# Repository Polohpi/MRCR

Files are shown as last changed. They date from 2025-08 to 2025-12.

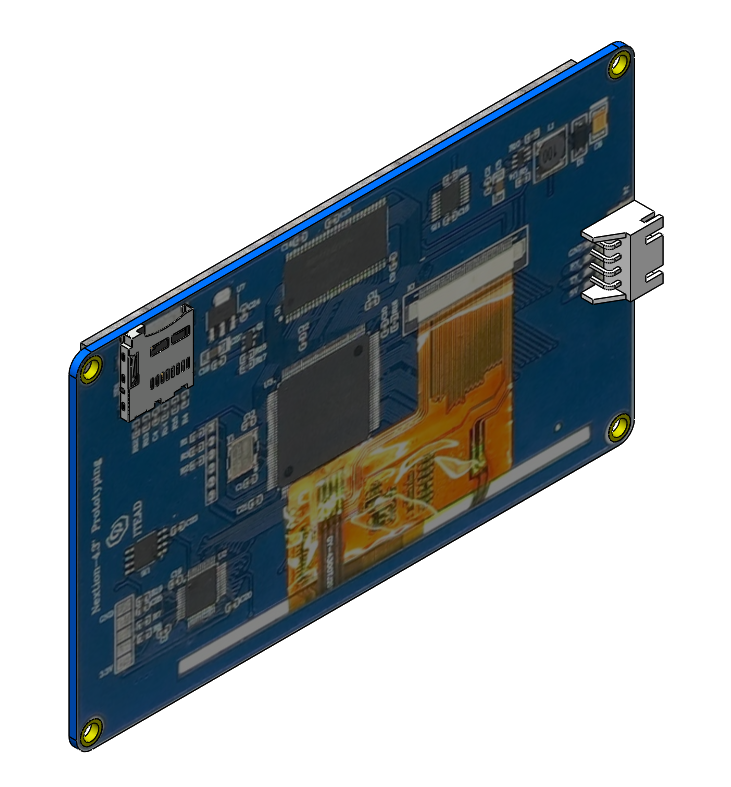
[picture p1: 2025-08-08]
Nextion/Sldprt/Capture3.PNG

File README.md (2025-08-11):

# MRCR
Banc de Rodage pour moteur Nitro

Arduino SAMD21 M0

using :

PID_v1 library            https://github.com/br3ttb/Arduino-PID-Library
Scheduler                 https://github.com/arduino-libraries/Scheduler
Easy Nextion Library      https://github.com/Seithan/EasyNextionLibrary
MovingAvg                  https://github.com/JChristensen/movingAvg

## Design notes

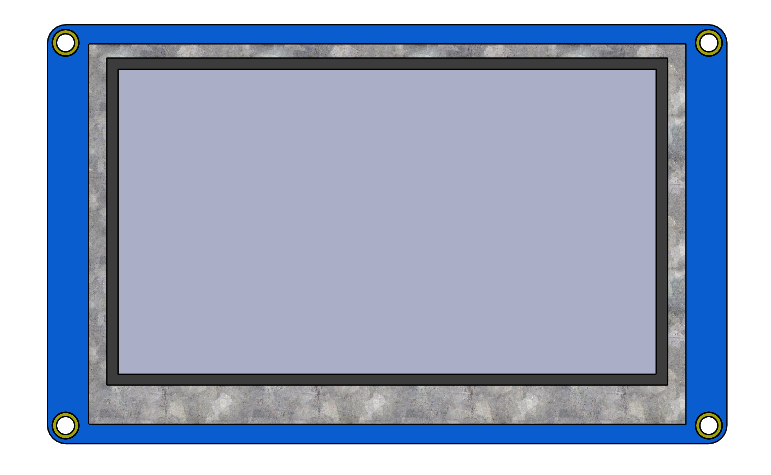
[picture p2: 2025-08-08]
Nextion/Sldprt/Capture1.PNG

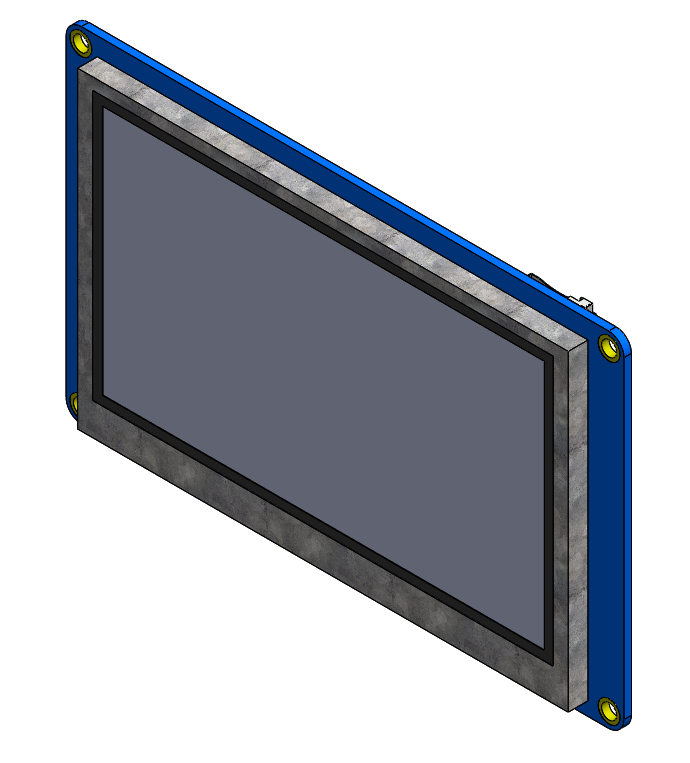
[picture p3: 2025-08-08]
Nextion/Sldprt/Capture2.PNG

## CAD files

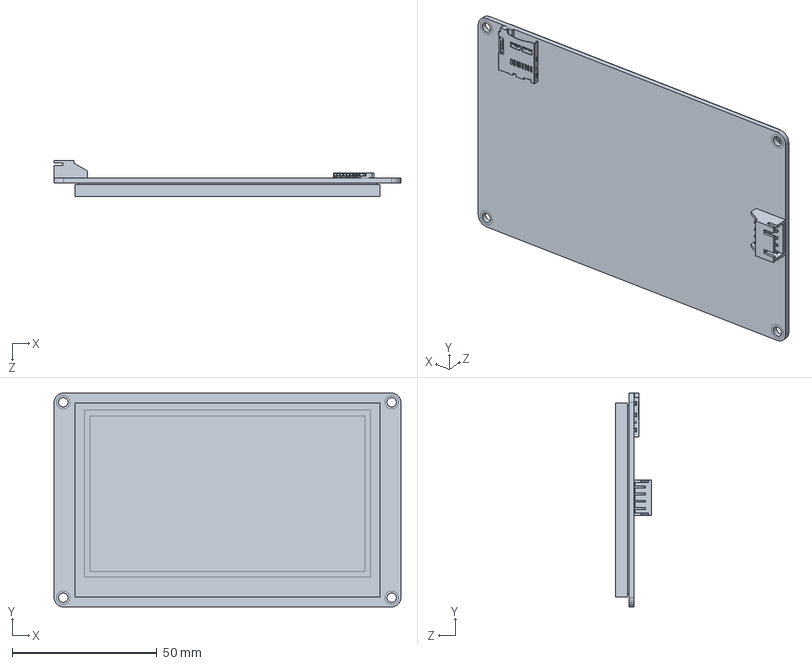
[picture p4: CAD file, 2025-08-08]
Nextion/Sldprt/Nextion - NX4827T043_011 - 4.3inch HMI LCD Screen.SLDPRT
120.0 x 74.0 x 12.5 mm

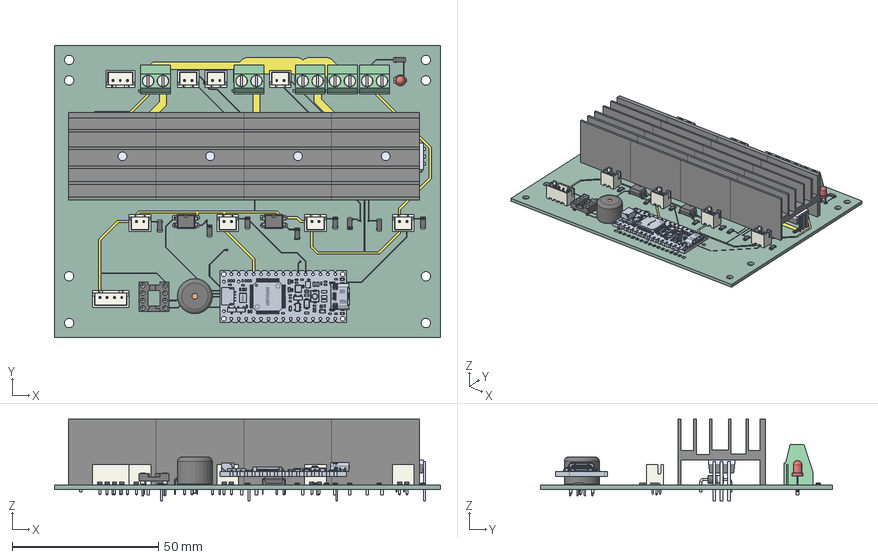
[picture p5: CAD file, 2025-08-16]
PCB/banc_rodage_pcb/banc_rodage_pcb.step
132.0 x 100.0 x 28.0 mm
R_1206_3216Metric x 11
banc_rodage_pcb 1.2.1
banc_rodage_pcb 1.2.2
banc_rodage_pcb 1.2.3
banc_rodage_pcb 1.2.4
banc_rodage_pcb 1.2.5
banc_rodage_pcb 1.2.6
banc_rodage_pcb 1.2.7
banc_rodage_pcb 1.2.8
banc_rodage_pcb 1.2.9
banc_rodage_pcb 1.2.10
banc_rodage_pcb 1.2.11
banc_rodage_pcb 1.2.12
banc_rodage_pcb 1.2.13
banc_rodage_pcb 1.2.14
banc_rodage_pcb 1.2.15
banc_rodage_pcb 1.2.16
banc_rodage_pcb 1.2.17
banc_rodage_pcb 1.2.18
banc_rodage_pcb 1.2.19
banc_rodage_pcb 1.2.20
banc_rodage_pcb 1.2.21
banc_rodage_pcb 1.2.22
banc_rodage_pcb 1.2.23
banc_rodage_pcb 1.2.24
banc_rodage_pcb 1.2.25
banc_rodage_pcb 1.2.26
banc_rodage_pcb 1.2.27
banc_rodage_pcb 1.2.28
banc_rodage_pcb 1.2.29
banc_rodage_pcb 1.2.30
banc_rodage_pcb 1.2.31
banc_rodage_pcb 1.2.32
banc_rodage_pcb 1.2.33
banc_rodage_pcb 1.2.34
banc_rodage_pcb 1.2.35
banc_rodage_pcb 1.2.36
banc_rodage_pcb 1.2.37
banc_rodage_pcb 1.2.38
banc_rodage_pcb 1.2.39
banc_rodage_pcb 1.2.40
banc_rodage_pcb 1.2.41
banc_rodage_pcb 1.2.42
banc_rodage_pcb 1.2.43
banc_rodage_pcb 1.2.44
banc_rodage_pcb 1.2.45
banc_rodage_pcb 1.2.46
banc_rodage_pcb 1.2.47
banc_rodage_pcb 1.2.48
banc_rodage_pcb 1.2.49
banc_rodage_pcb 1.2.50
banc_rodage_pcb 1.2.51
banc_rodage_pcb 1.2.52
banc_rodage_pcb 1.2.53
banc_rodage_pcb 1.2.54
banc_rodage_pcb 1.2.55
banc_rodage_pcb 1.2.56
banc_rodage_pcb 1.2.57
banc_rodage_pcb 1.2.58
banc_rodage_pcb 1.2.59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

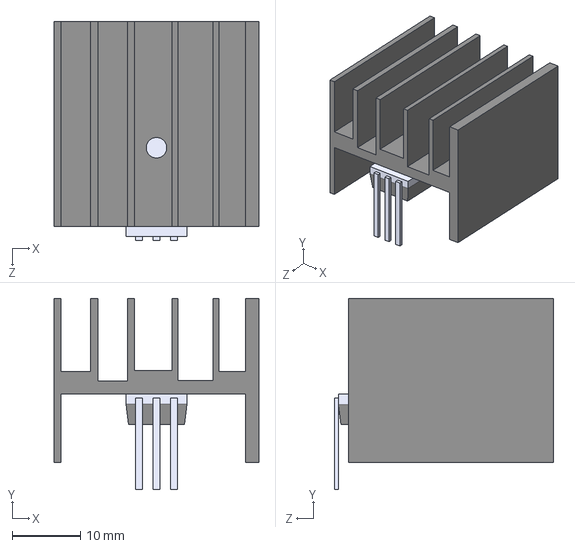
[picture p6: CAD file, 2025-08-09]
PCB/kicad library/Part1.STEP
30.0 x 28.0 x 32.1 mm

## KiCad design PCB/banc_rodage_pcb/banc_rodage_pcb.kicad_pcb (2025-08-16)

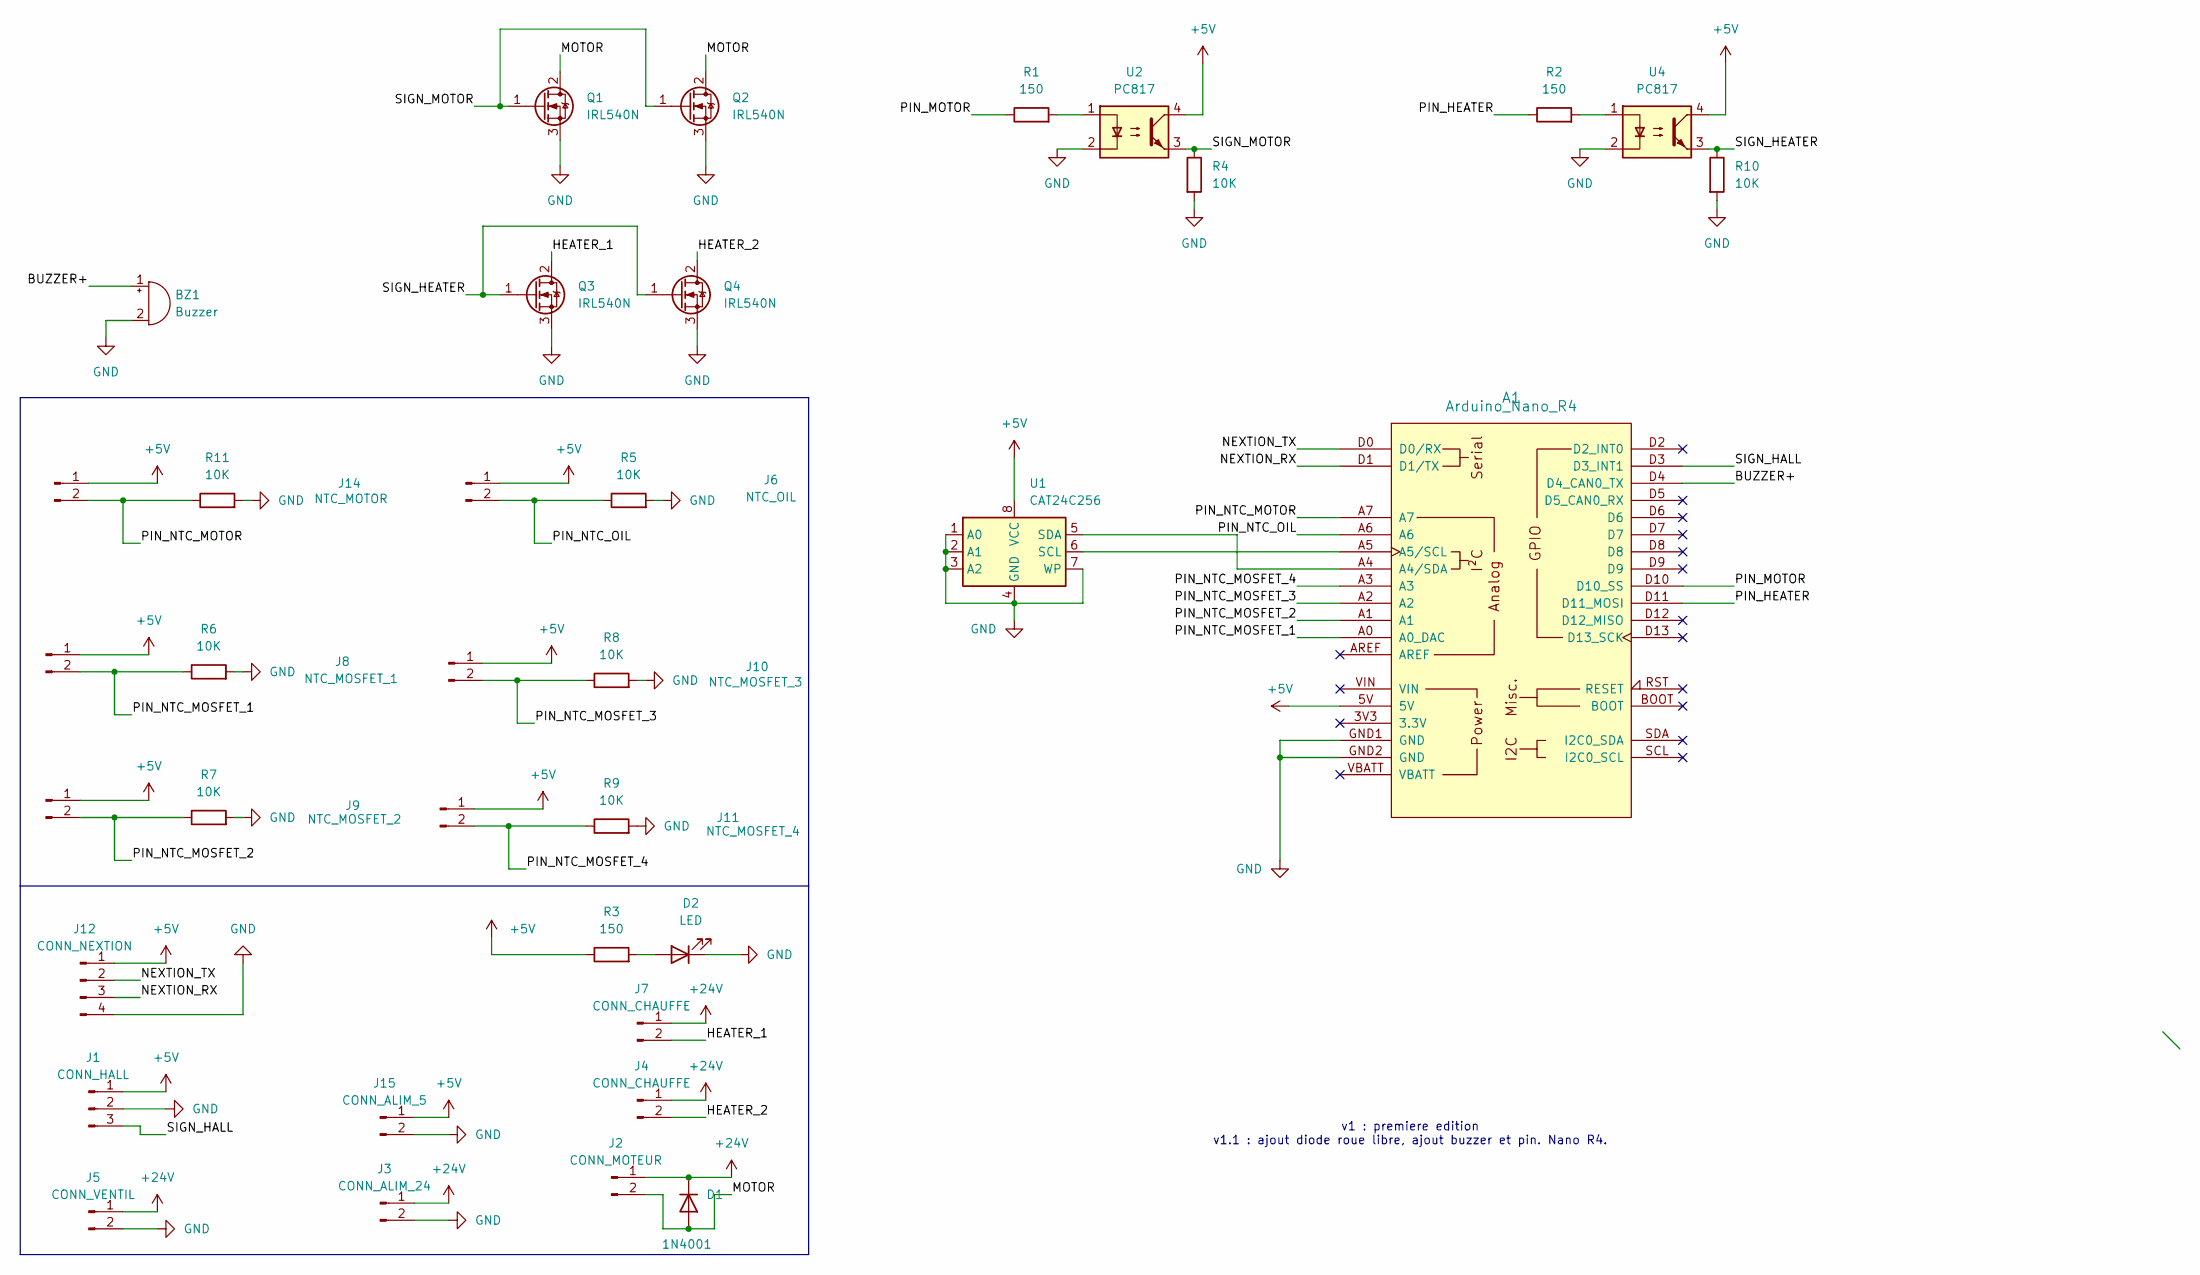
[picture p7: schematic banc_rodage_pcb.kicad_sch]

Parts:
A1: Arduino_Nano_R4
BZ1: Buzzer; Buzzer_12x9.5RM7.6
D1: 1N4001; D_DO-41_SOD81_P10.16mm_Horizontal
D2: LED; LED_D3.0mm
J1: CONN_HALL; JST_XH_B3B-XH-A_1x03_P2.50mm_Vertical
J2: CONN_MOTEUR; TerminalBlock_bornier-2_P5.08mm
J3: CONN_ALIM_24; TerminalBlock_bornier-2_P5.08mm
J4, J7: CONN_CHAUFFE; TerminalBlock_bornier-2_P5.08mm
J5: CONN_VENTIL; JST_XH_B2B-XH-A_1x02_P2.50mm_Vertical
J6: NTC_OIL; JST_XH_B2B-XH-A_1x02_P2.50mm_Vertical
J8: NTC_MOSFET_1; JST_XH_B2B-XH-A_1x02_P2.50mm_Vertical
J9: NTC_MOSFET_2; JST_XH_B2B-XH-A_1x02_P2.50mm_Vertical
J10: NTC_MOSFET_3; JST_XH_B2B-XH-A_1x02_P2.50mm_Vertical
J11: NTC_MOSFET_4; JST_XH_B2B-XH-A_1x02_P2.50mm_Vertical
J12: CONN_NEXTION; JST_XH_B4B-XH-A_1x04_P2.50mm_Vertical
J14: NTC_MOTOR; JST_XH_B2B-XH-A_1x02_P2.50mm_Vertical
J15: CONN_ALIM_5; TerminalBlock_bornier-2_P5.08mm
Q1, Q2, Q3, Q4: IRL540N; TO-220F-3_Horizontal_TabUp
R1, R2, R3: 150; R_1206_3216Metric
R4, R5, R6, R7, R8, R9, R10, R11: 10K; R_1206_3216Metric
U1: CAT24C256; DIP-8_W7.62mm_Socket
U2, U4: PC817; DIP-4_W7.62mm

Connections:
+5V: A1.5V, J1.1, J6.1, J8.1, J9.1, J10.1, J11.1, J12.1, J14.1, J15.1, R3.1, U1.8 (VCC), U2.4, U4.4
+24V: D1.1 (K), J2.1, J3.1, J4.1, J5.1, J7.1
/BUZZER+: A1.D4 (D4_CAN0_TX), BZ1.1 (+)
/HEATER_1: J7.2, Q3.2 (D)
/HEATER_2: J4.2, Q4.2 (D)
/MOTOR: D1.2 (A), J2.2, Q1.2 (D), Q2.2 (D)
/NEXTION_RX: A1.D1 (D1/TX), J12.3
/NEXTION_TX: A1.D0 (D0/RX), J12.2
/PIN_HEATER: A1.D11 (D11_MOSI), R2.1
/PIN_MOTOR: A1.D10 (D10_SS), R1.1
/PIN_NTC_MOSFET_1: A1.A0 (A0_DAC), J8.2, R6.1
/PIN_NTC_MOSFET_2: A1.A1, J9.2, R7.1
/PIN_NTC_MOSFET_3: A1.A2, J10.2, R8.1
/PIN_NTC_MOSFET_4: A1.A3, J11.2, R9.1
/PIN_NTC_MOTOR: A1.A7, J14.2, R11.1
/PIN_NTC_OIL: A1.A6, J6.2, R5.1
/SIGN_HALL: A1.D3 (D3_INT1), J1.3
/SIGN_HEATER: Q3.1 (G), Q4.1 (G), R10.1, U4.3
/SIGN_MOTOR: Q1.1 (G), Q2.1 (G), R4.1, U2.3
GND: A1.GND1 (GND), A1.GND2 (GND), BZ1.2 (-), D2.1 (K), J1.2, J3.2, J5.2, J12.4, J15.2, Q1.3 (S), Q2.3 (S), Q3.3 (S), Q4.3 (S), R4.2, R5.2, R6.2, R7.2, R8.2, R9.2, R10.2, R11.2, U1.1 (A0), U1.2 (A1), U1.3 (A2), U1.4 (GND), U1.7 (WP), U2.2, U4.2
unnamed: A1.A4 (A4/SDA), U1.5 (SDA)
unnamed: A1.A5 (A5/SCL), U1.6 (SCL)
unnamed: D2.2 (A), R3.2
unnamed: R1.2, U2.1
unnamed: R2.2, U4.1

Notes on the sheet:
v1 : premiere edition v1.1 : ajout diode roue libre, ajout buzzer et pin. Nano R4.

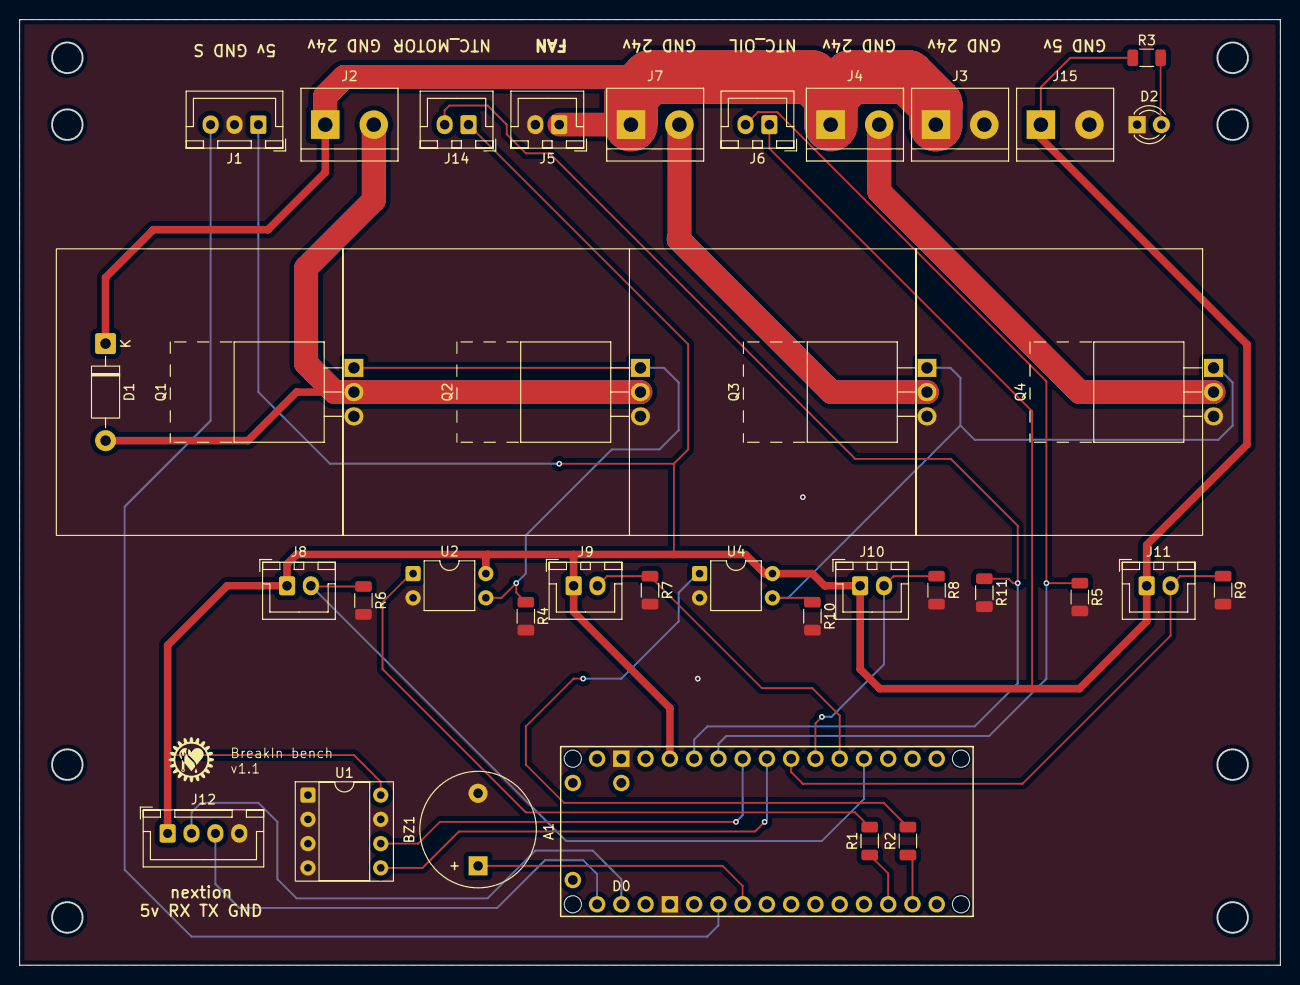
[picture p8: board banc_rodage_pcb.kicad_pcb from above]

Board: 2 copper layers, 132.0 x 99.0 mm, 36 parts (0 on the bottom side), 25 nets.

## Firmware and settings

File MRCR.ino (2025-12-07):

#include "lib_variable.h"
#include "function_software.h"
#include "function_hardware.h"
#include "page.h"
#include "function_nextion.h"



void setup() {
  
  analogWriteResolution(12); //14 because 16 make the PID and the motor very very long to respond
  Serial.begin(9600);
  Nextion.begin(9600); // Begin the object with a baud rate of 9600


  Serial.println("Setup");
  Scheduler.startLoop(ntc_update);
  Scheduler.startLoop(backend_nextion);
  Scheduler.startLoop(MOTOR_PID);
  Scheduler.startLoop(RPM_update);
  Scheduler.startLoop(HEAT_ramp);
  Scheduler.startLoop(debug, 2048);
  Scheduler.startLoop(Manual_Timer);
  Scheduler.startLoop(Security);
  Scheduler.startLoop(MainPage);
  Scheduler.startLoop(ManualModePage);


  Motor_PID.SetMode(AUTOMATIC);

  Motor_PID.SetOutputLimits(0, 6700); //see backend_PID()
  
  Avg_Temp_ntc_oil.begin(); // start movingavg for heating, motor and ntc sensor
  Avg_MotorRPM.begin();
  Avg_Temp_ntc_mosfet_motor_1.begin();
  Avg_Temp_ntc_mosfet_motor_2.begin();
  Avg_Temp_ntc_motor.begin();
  Avg_Temp_ntc_mosfet_heat_1.begin();
  Avg_Temp_ntc_mosfet_heat_2.begin();
  Avg_MotorRPM.reset();

  pinMode(PIN_NTC_MOSFET_MOTOR_1, INPUT);      // set pinmode
  pinMode(PIN_NTC_MOSFET_MOTOR_2, INPUT);
  pinMode(PIN_NTC_MOSFET_HEAT_1, INPUT);
  pinMode(PIN_NTC_MOSFET_HEAT_2, INPUT);
  pinMode(PIN_NTC_MOTOR, INPUT); //pullup here to avaoid erratic reaing before the pcb v2 wich will include a ntc sensor for the DC motor itself
  pinMode(PIN_NTC_OIL, INPUT);
  pinMode(PIN_MOTOR, OUTPUT);
  pinMode(PIN_HEATER, OUTPUT); 
  pinMode(PIN_IR_SENSOR, INPUT_PULLUP);

  attachInterrupt(digitalPinToInterrupt(PIN_IR_SENSOR), RPM_interrupt, FALLING);
  yield();
  delay(2000);
}

void loop() 
{

  if(MAIN_PAGE == false && MANUAL_MODE_PAGE == false)
  {
  Nextion.writeStr("page Main");
  MAIN_PAGE = true;
  }
  yield();
}

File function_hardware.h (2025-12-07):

#ifndef FUNCTION_HARDWARE_H
#define FUNCTION_HARDWARE_H


void MOTOR_PID();
void backend_nextion();
void ntc_update();
void RPM_interrupt();
void HEAT_ramp();



//compute the PID for the motor
void MOTOR_PID()
{
  if( (millis() - Motor_PID_refresh_timer) > MOTOR_PID_REFRESH_TIME)
  {

      if(Motor_Setpoint == 0)
      {
        /*
        The PID library doesnt include a function to force the pid output to 0. The output only change based on the input and tthe output.
        This means when we set output == 0 when Setpoint == 0 (to stop the motor), the ouput comput from the pid dont go to 0.
        Logic : the RPM = 0 and the setpoint = 0 so no need the change the output. We will lure the PID with a constant high RPM so it will go to 0.
        */
        Motor_PID.Compute();
      }
      else
      {
        if(Emergency_stop == false)
        {
          Motor_PID.Compute();
        }
      }
      analogWrite(PIN_MOTOR, (Motor_Output/10)*( (Motor_Output/6000)*(Motor_Output/6000)* 20) ); 
      Motor_PID_refresh_timer = millis();

      /* this weird line is not my fault I promess. 
      The problem is : the pid can control most of the speed of the motor (0 RPM<output<~ 550 RPM) 
      but can not manage to get the motor to run to 1200 RPM. This take ages.
      This was the only solution I got to work without make the PID unstable. So i fix it with some duck tape I guess */
    
  } 
  yield();

}

//manage all global data flow between MCU and nextion
void backend_nextion()
{
  if( (millis() - nextion_response_refresh_timer) > NEXTION_RESPONSE_REFRESH_TIME)
  {
    //send current RPM and oil temp
    Nextion.writeNum("GLB_VAL.CUR_RPM.val", avg_Motor_RPM);
    Nextion.writeNum("GLB_VAL.CUR_HEAT.val",  avg_temp_ntc_oil);

    //send all temp values from security NTC sensor
    Nextion.writeNum("GLB_VAL.NTC_MTR1.val",  avg_temp_ntc_mosfet_motor_1);
    Nextion.writeNum("GLB_VAL.NTC_MTR2.val",  avg_temp_ntc_mosfet_motor_2);
    Nextion.writeNum("GLB_VAL.NTC_MTR.val",  avg_temp_ntc_motor);
    Nextion.writeNum("GLB_VAL.NTC_HTR1.val",  avg_temp_ntc_mosfet_heat_1);
    Nextion.writeNum("GLB_VAL.NTC_HTR2.val",  avg_temp_ntc_mosfet_heat_1);

    //send PID output
    Nextion.writeNum("GLB_VAL.MTR_OTP.val",  Motor_Output);
    Nextion.writeNum("GLB_VAL.IR_SNSR.val",  IR_sensor_count);
    Nextion.writeStr("GLB_VAL.HEAT_STE.txt",  digitalRead(PIN_HEATER) ? "ON" : "OFF");


    current_year = Nextion.readNumber("GLB_VAL.CUR_YEAR.val");
    current_month = Nextion.readNumber("GLB_VAL.CUR_MONTH.val");
    current_day = Nextion.readNumber("GLB_VAL.CUR_DAY.val");
    current_hour = Nextion.readNumber("GLB_VAL.CUR_HOUR.val");
    current_minute = Nextion.readNumber("GLB_VAL.CUR_MIN.val");
    current_second = Nextion.readNumber("GLB_VAL.CUR_SEC.val");

    Nextion.NextionListen();
    nextion_response_refresh_timer = millis();
  }
  yield();
}


//update all ntc temperature
void ntc_update()
{
  if( (millis() - NTC_refresh_timer) > NTC_REFRESH_TIME)
  {
    avg_temp_ntc_oil = Avg_Temp_ntc_oil.reading(ReadTempNTC(PIN_NTC_OIL));
    avg_temp_ntc_motor = Avg_Temp_ntc_motor.reading(ReadTempNTC(PIN_NTC_MOTOR));
    avg_temp_ntc_mosfet_motor_1 = Avg_Temp_ntc_mosfet_motor_1.reading(ReadTempNTC(PIN_NTC_MOSFET_MOTOR_1));
    avg_temp_ntc_mosfet_motor_2 = Avg_Temp_ntc_mosfet_motor_2.reading(ReadTempNTC(PIN_NTC_MOSFET_MOTOR_2));
    avg_temp_ntc_mosfet_heat_1 = Avg_Temp_ntc_mosfet_heat_1.reading(ReadTempNTC(PIN_NTC_MOSFET_HEAT_1));
    avg_temp_ntc_mosfet_heat_2 = Avg_Temp_ntc_mosfet_heat_2.reading(ReadTempNTC(PIN_NTC_MOSFET_HEAT_2));
  }
  yield();
}

//interrupt to add one touth from the dc motor target
void RPM_interrupt()
{
  IR_sensor_count++;
}
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

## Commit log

2024-11-28 scheduler + NTC
    implementation from scratch of the NTC temp sensor and the first scheduler loop
2025-08-08 PID motor in progress but not finished. Nextion and NTC OK
    [Nextion - NX4827T043_011 - 4.3inch HMI LCD Screen.SLDPRT]
2025-08-08 working motor PID
2025-08-09 Added Kicad Files. Addes many page for the menu. Work in progress
    [Part1.STEP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]
2025-08-11 add a debug loop. Start working on the heating PIDs. Nextion : moving the the 4.3 inch screen. Started Settings menu to set the Nextion RTC. Started diagnostic menus with sensors values. Global look 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
2025-08-13 working motor PID on the R4. Keep pushing paul keep pushing.
2025-08-13 heater controls OK using a simple ON OFF system
2025-08-16 cleanup. automode : gestion of brenkin profile with the sd card (rename, duplicate, delete) is ok
    [Part1.STEP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]
2025-08-29 pcb v1.1 validated. every things works as expected. New screen received. keep pushing keep pushing
    [banc_rodage_pcb-F_Silkscreen.gbr]
2025-12-07 added timer function for the manual mode
2025-12-07 added basic security functions. rework of the way pages are handle. no more loop in other loop. Everyhting works with true false flags. all pages are now executed with scheduler loop
    [MRCR.ino, function_hardware.h, function_software.h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]
